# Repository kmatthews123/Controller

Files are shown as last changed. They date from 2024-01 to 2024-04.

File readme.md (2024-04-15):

# Custom ROV Controller

###### What is this project?

I designed this controller as a combination of work project and learning tool

The original genesis of this project was a whacky controller thought up during many long hours of driving with myself and a co-worker. I decided to build a custom ROV controller based on a guitar hero controller for laughs. The controller was a lot easier to build than I thought it would be and it was a very fun thing at my work Christmas party. 

The Guitar hero controller utilized all the buttons used by default on the guitar, I had to add a linear Potentiometer for the vertical propellor as well as the "whammy bar" as a self centering vertical propellor controller. I also added the joystick to the guitar. This was a fun project and while I did learn some stuff about circuit python I defiantly did not plan to use this for more than a gag.

#### The Real Controller



This controller was designed for use with a video ray pro4 ROV as a more comfortable and normal user interface device.

 I work at a company that uses a pro4 to inspect submerged structures. I found that the default controller from Video Ray is really uncomfortable to use for a full day and its design made it difficult for me to use during complex movements and actions. The  original controller (seen below)  shows up as a USB game-pad to the laptop that is used to communicate with the ROV. This computer uses windows 10 and using the USB controller utility included in windows I was able to map out how the video ray controller button map is seen by the system. From what I understand the pro4 has two compatible controllers, the normal industrial controller that my company normally uses and also the Logitech Cordless RumblePad 2 which is an old controller. Apparently you can edit xml files to make other controllers work with the pro4 but as engineering support has ended for this bot, I was left with the options of editing xml files that could potentially make my pro4 console unusable if i did something wrong (not an option as this is a work machine), download software to  remap the controller using software (This option was unappealing because I found this kind of software to be really hit and miss for the functions that I needed to setup) or design my own custom controller. 

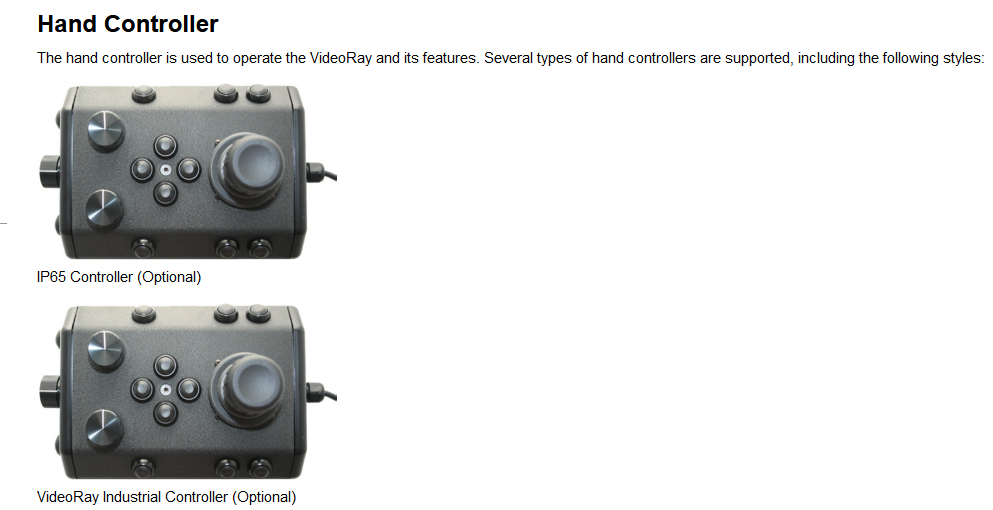
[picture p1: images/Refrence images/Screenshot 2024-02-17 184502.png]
Videoray default controller


I learned to use KiCAD 7.0 to design the custom PCB for this project. I have dabbled with electronics and code for years and have made several custom breadboards but the step to making my own distinct PCB was really interesting. The community for KiCad was very beginner friendly, and once I started to understand the structure of the program and the workflow the process began to make a lot of sense. I did do two different versions of this board. with the first version I was manually routing traces between my components and I realized that that was going to take way too long and for this application it didn't make much sense so I ended up auto routing the rest of the project. This worked fine though I do think that there are definitely routing things I could have improved.

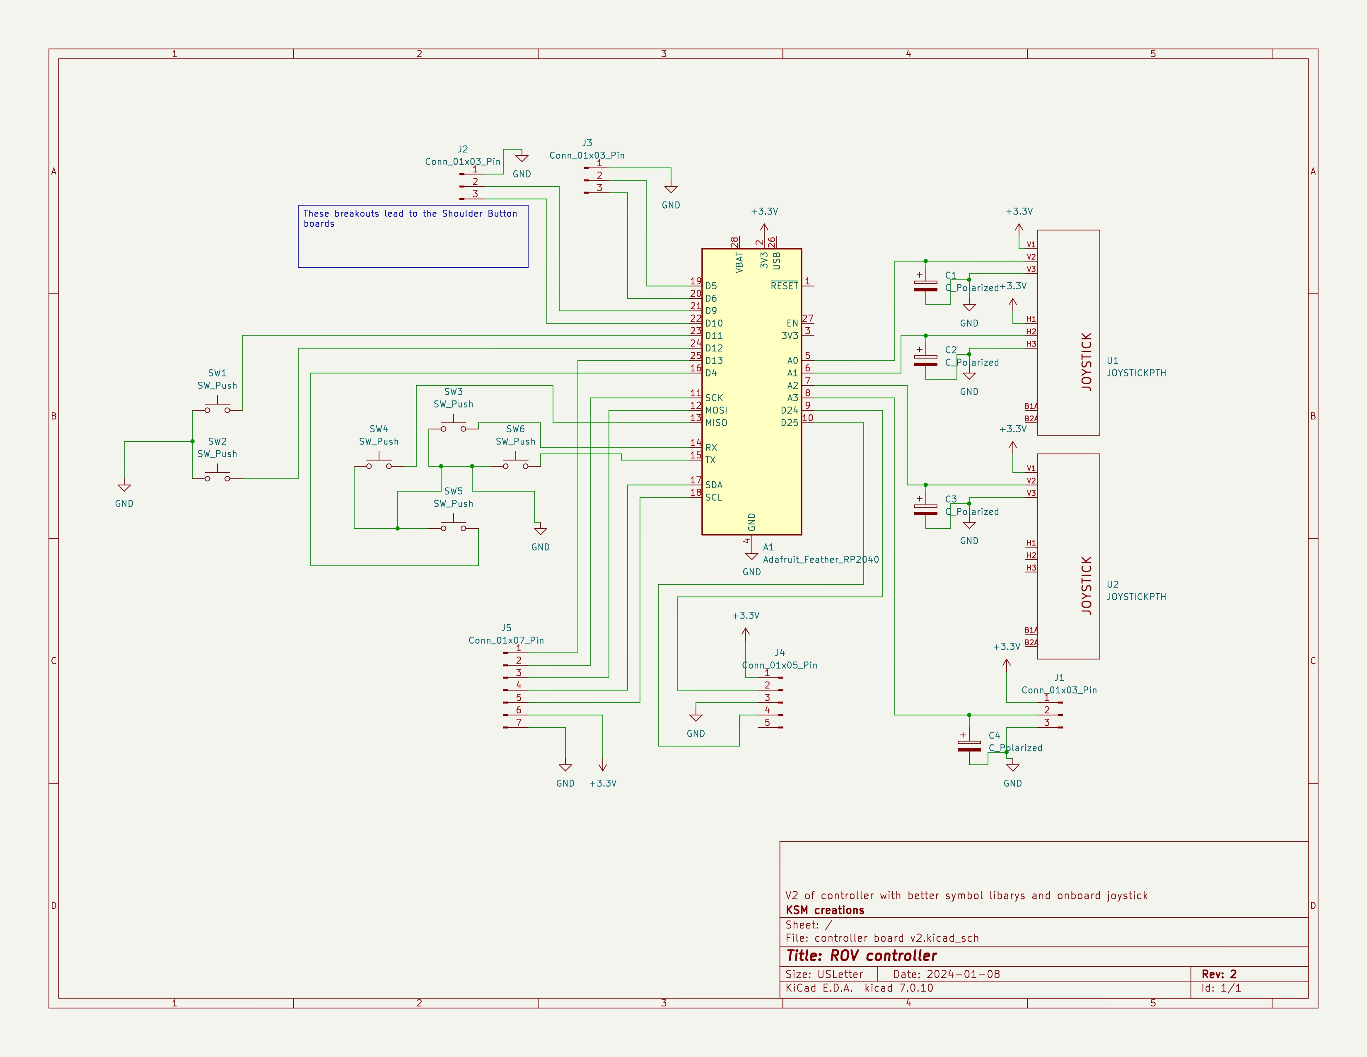
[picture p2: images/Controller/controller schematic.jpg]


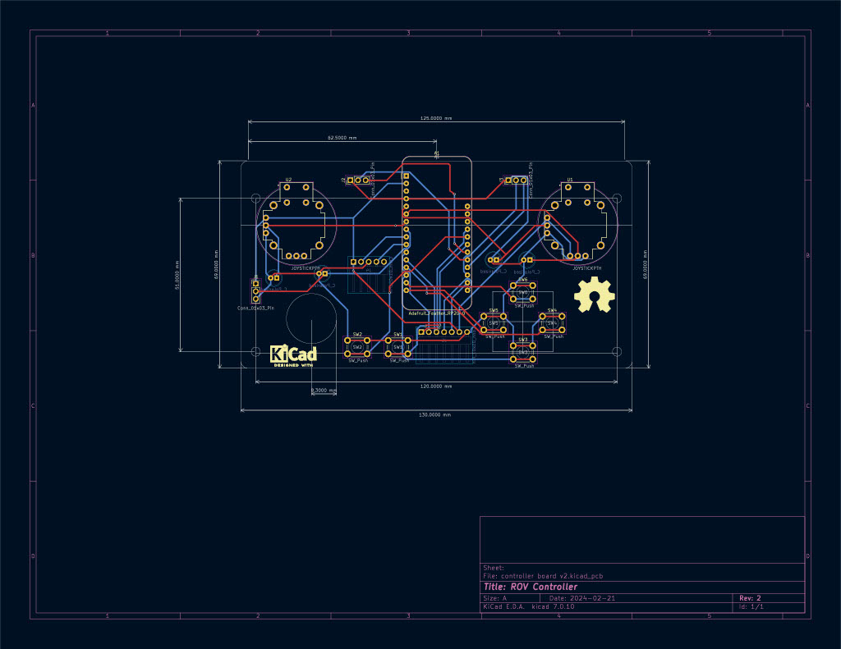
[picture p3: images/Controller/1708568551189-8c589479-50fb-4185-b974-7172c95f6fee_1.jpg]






 I also did not know how PCB manufacturers price out boards based on the amount of area that each board will take up in the batching process. Because of these things I found that I could save a bunch of money by making two distinct boards with one being the primary controller and the other being used for the shoulder buttons. the shoulder button board breaks in half for each side of the controller and everything is "wired" up really simply. I think adding an I2C analog input expansion board would have been a useful addition for this board (more on that later). I used OSH Park ~ for my PCB manufacturer because it was super easy to upload my KiCAD files to get them manufactured and the quality seems to be very good of the received circuit boards.

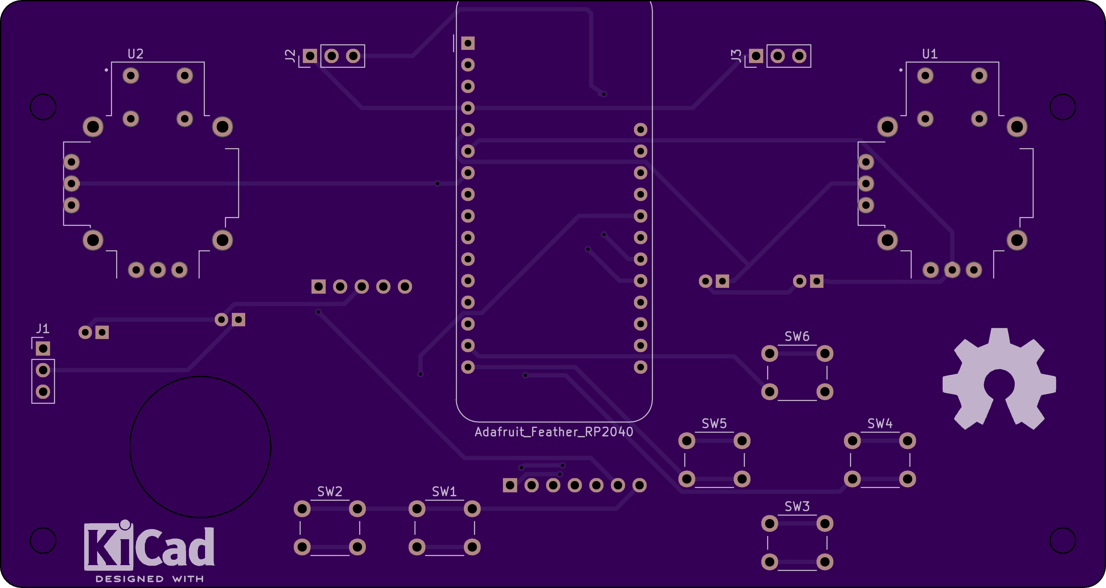
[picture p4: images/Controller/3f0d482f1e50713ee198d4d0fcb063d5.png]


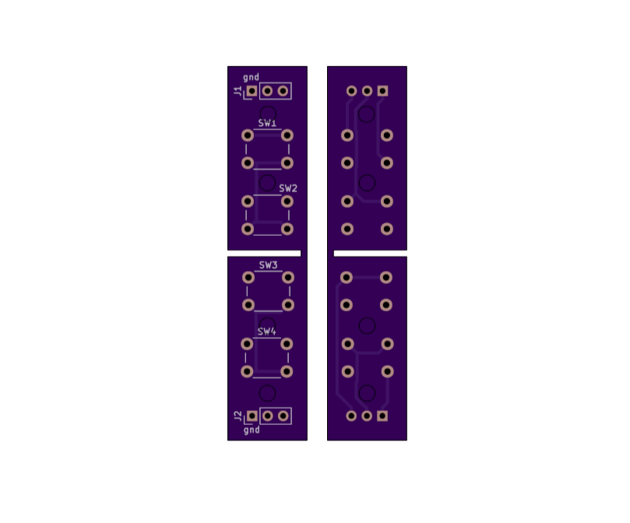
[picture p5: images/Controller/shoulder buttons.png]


For designing the body of the controller, I used an online CAD program called OnShape. I took a fairly simple approach to this and imported all the boards and as many components as i could find models for, then built an assembled circuit board in an assembly. From there I used dimensions of the board to layout the base of the controller, and designed the front plate as a piece used to hold the shoulder buttons. The shoulder buttons are admittedly a bit rough; I considered a bunch of different ways of designing the buttons and I think the method I used is ok if I had executed it a bit better. If I were to do a full redesign I would probably do something more similar to paddles instead of the straight push buttons I ended up with. Lastly I designed the face plate of the controller based off the PCB assembly I had built before. OnShape has a really neat feature that allows for referencing assemblies in a part design workflow. this was really handy for designing parts in reference to other more complicated items. 

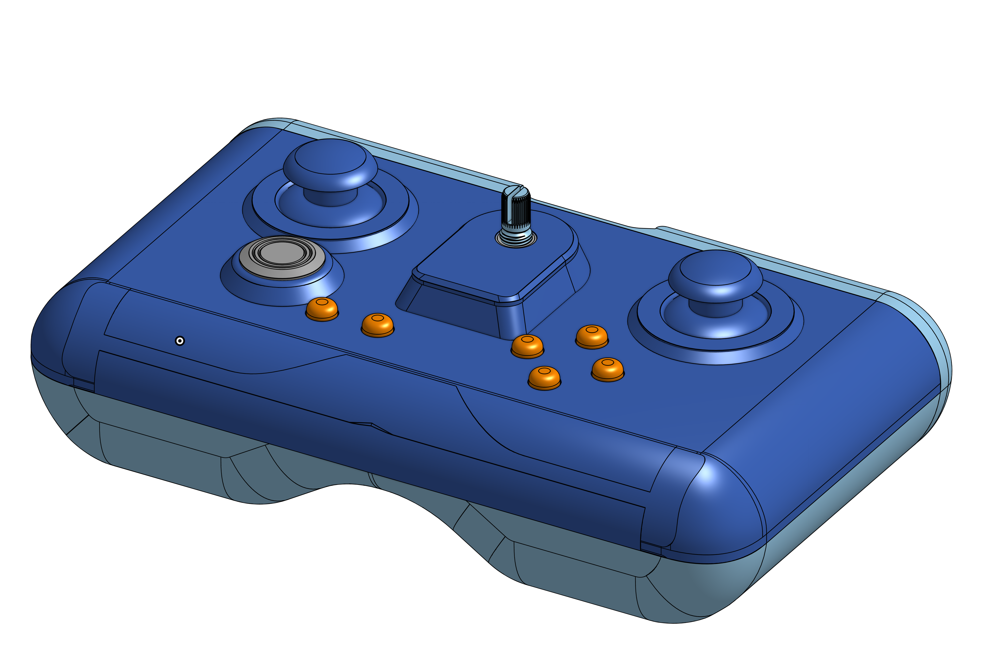
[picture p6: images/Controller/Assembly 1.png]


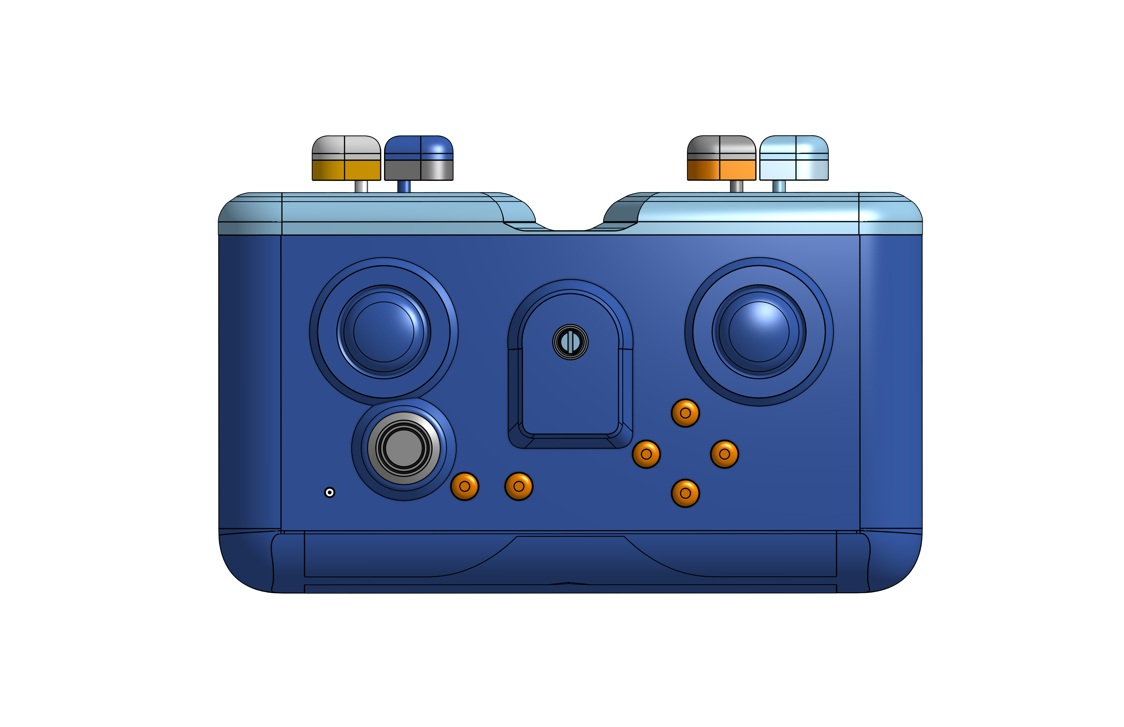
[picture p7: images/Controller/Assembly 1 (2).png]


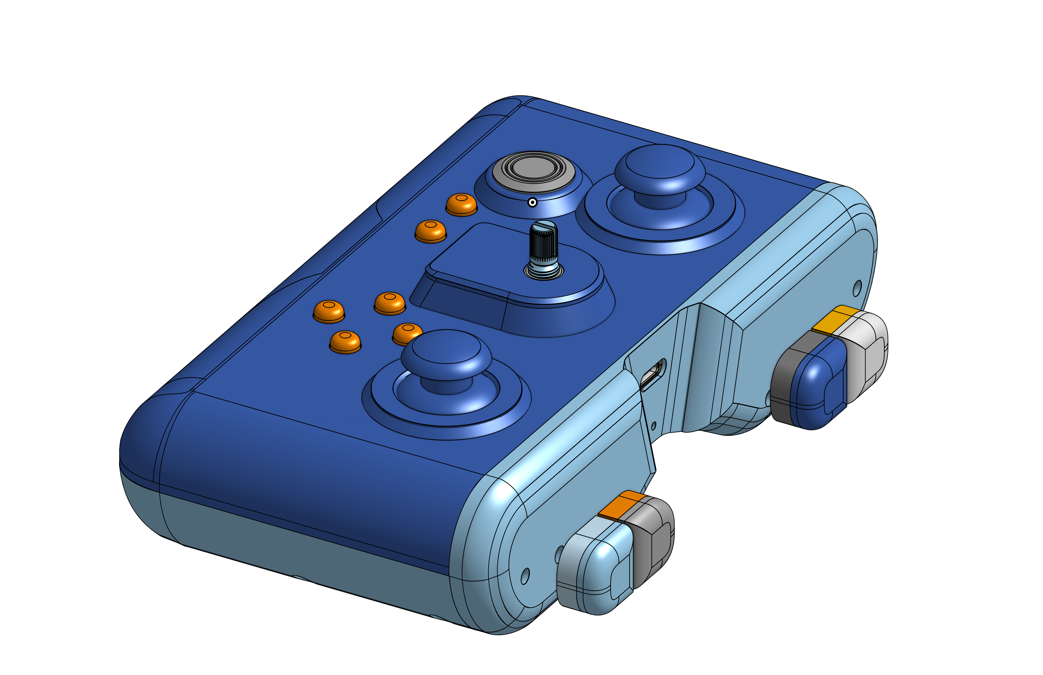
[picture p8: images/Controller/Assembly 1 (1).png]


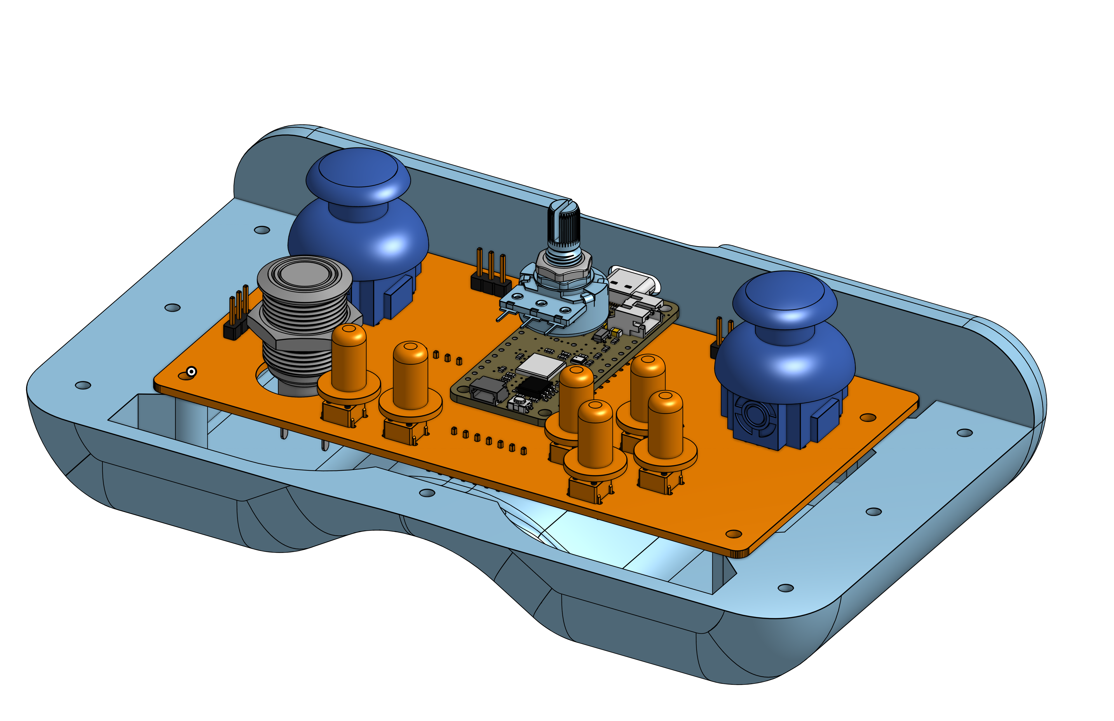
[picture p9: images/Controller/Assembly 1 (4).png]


The CAD for this project is available in the 3d Models folder for both .step files and .3mf files. To view, copy and mess around with my original cad models checkout the below OnShape link.

https://cad.onshape.com/documents/9419f7314355fc0529143749/w/7dd750f9077cb0f159653e8e/e/9448de140bcc603a1d0b7df0

###### The electronics used

- RP2040 Adafruit Feather board

- with generic joysticks bought on digikey (COM-09032),

-  10 generic push buttons (6mm button height),

-  4 electrolytic capacitors to smooth joystick motion (47 Farad) 

- 1 10k linear POT. 

- an assortment of DuPont headers

###### The code!

The code for this project relies heavily on an awesome library called 
joystick_XL for circuit python. if you want to build a project like this one a great starting point is this GitHub and associated documentation.

 [GitHub - fasteddy516/CircuitPython_JoystickXL: Turn a CircuitPython device into a joystick controller with lots of inputs.](https://github.com/fasteddy516/CircuitPython_JoystickXL) 

I also ended up using some logic to switch inputs from a joystick on the right side to the potentiometer in the middle of the controller. This switch is useful because I found that I wanted a self centering vertical thruster control. For the Pro4 this means that when you are not actively using the controller the vertical propellor will be off. We set the pro4 to be neutrally buoyant when in fresh water. If you want to use the vertical propellor when not actually touching the controller (very useful for certain actions, motions and when lifting on items during an inspection). 

For those unfamiliar with the somewhat complicated process of building a USB HID device this library and circuit python in general makes things really easy. I can see lots of use cases for this library with all manner of custom interface devices and I could see this project acting as a good starting point for anyone trying to do something similar.

If you have a pro4 or another Video Ray device, there are a few changes I would make before trying to replicate this project 1:1. I don't plan on doing that for myself, but please reach out if you want to make your own, as I wouldn't mind sharing thoughts on an improved v2.

###### Lessons Learned and things to improve

- I should have used a micro controller with one additional analog input pin. This would have added flexibility for modifying the controller config. I find that I want to use the left hand controller for vertical movement and also for yaw and using the right stick for going forward and back. The current controller doesn't have the Y axis on the left hand stick connected to anything currently because I had to have the set and forget vertical propellor as an option. I think next time I would use something more like the Adafruit Feather M4 Express as it would have enough digital pins and enough analog IO to get the job done. this micro controller is a bit more spendy and I could also see using the Adafruit Feather 32u4 as a cheaper alternative. Basically something with the same pinout and more analog pins while still having at least 12 digital pins onboard. 

- The shoulder buttons are not very good. I think I could have planned those better and I think that next time I would use something more like a standard keyboard switch for the shoulder buttons or something like a simple paddle that would push on the head of a simple button. 

- I would like to explore a wireless version of this device at some point but this is pretty far down my list of priorities. 



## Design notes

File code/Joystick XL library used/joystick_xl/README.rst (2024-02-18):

JoystickXL for CircuitPython
============================








Description
===========
This CircuitPython driver simulates a *really big* USB HID joystick device - up
to 8 axes, 128 buttons and 4 hat (POV) switches.  If you want to build a custom
game controller with a lot of inputs - *I'm looking at you, space/flight sim
pilots, racing sim drivers and virtual farmers* - JoystickXL can help.

Requirements
============
*This driver relies on features that were introduced in CircuitPython
version 7.x*  **You must be running CircuitPython 7.0.0 or newer
on your device in order to use JoystickXL.**

* This driver was made for devices running `Adafruit CircuitPython <https://www.adafruit.com/circuitpython>`_.
  For a list of compatible devices, see `circuitpython.org <https://circuitpython.org/downloads>`_.

* There are no dependencies on any other CircuitPython drivers, libraries or modules.

* Pre-compiled (``.mpy``) versions of JoystickXL are available in the `releases <https://github.com/fasteddy516/CircuitPython_JoystickXL/releases>`_
  section for CircuitPythons version 8.x and 9.x.  

Limitations
===========
* A wired USB connection to the host device is required.  *Bluetooth
  connectivity is not supported at this time.*

* Axis data is reported with 8-bit resolution (values ranging from 0-255).

* Only one JoystickXL device can be defined per CircuitPython board.  *You
  cannot have a single board report as two or more independant joysticks.*

* JoystickXL's reporting frequency - thus, input latency - is affected by
  many factors, including processor speed, the number of inputs that need
  to be processed, and the latency of any external input peripherals that
  are being used.  The reporting frequency is going to be significantly
  higher on a Metro M4 Express using on-board GPIO than it is on a QT-PY
  using I2C/SPI-based I/O expanders. 

Host OS/Software Compatibility
==============================
On **Windows 10/11**, all 8 axes 128 buttons and 4 hat switches are supported at
the operating system level, and JoystickXL has been tested and confirmed to work
with the following games:

* **Microsoft Flight Simulator (2020)** *(All inputs)*
* **Elite Dangerous** *(Limited to 32 buttons)*
* **Star Citizen** *(All inputs)*
* **Digital Combat Simulator (DCS) World** *(All inputs)*
* **EverSpace 2** *(All inputs - hat switches are considered to be axes)*
* **Forza Horizon 4** *(All inputs)*
* **BeamNG.drive** *(Limited to 7 axes and 1 hat switch)*
* **Farming Simulator 19** *(Limited to 7 axes, 24 buttons and 1 hat switch)*

*Note that any game-specific input limitations mentioned above are - to the
best of my knowledge - a result of the game's joystick implementation, and are
not unique to JoystickXL.*

On **Linux**, a very limited amount of testing has been done on a Raspberry Pi
4B using ``jstest`` (part of the ``joystick`` package).  The first 7 axes and
80 buttons work correctly.  Axis 8 does not register any events, nor do any
buttons beyond the first 80.  Only a single hat switch *sort of* works, but it
gets interpreted as two axes rather than an actual hat switch.  Other Linux
platforms/distributions/applications have not been tested.

No testing has been done on an **Apple/Mac** platform.

Documentation
=============
Full documentation is available at `<https://circuitpython-joystickxl.readthedocs.org>`_.

Installation
============
1. Download the `latest release of JoystickXL <https://github.com/fasteddy516/CircuitPython_JoystickXL/releases/latest>`_
   that corresponds to the version of CircuitPython you're running.  (i.e.
   ``joystick_xl_x.x.x_cp8`` for CircuitPython 8.x)
2. Extract the files from the downloaded .zip archive.
3. Copy the ``joystick_xl`` folder to the ``lib`` folder on your device's
   ``CIRCUITPY`` drive.

For additional information on installing libraries, see Adafruit's
`Welcome to CircuitPython Guide <https://learn.adafruit.com/welcome-to-circuitpython/circuitpython-libraries>`_.

Using JoystickXL
================
1. Create/modify ``boot.py`` on your CircuitPython device to enable the
   required custom USB HID device.

   .. code:: python

      """boot.py"""
      import usb_hid
      from joystick_xl.hid import create_joystick

      # enable default CircuitPython USB HID devices as well as JoystickXL
      usb_hid.enable(
        (
          usb_hid.Device.KEYBOARD,
          usb_hid.Device.MOUSE,
          usb_hid.Device.CONSUMER_CONTROL,
          create_joystick(axes=2, buttons=2, hats=1),
        )
      )

2. Use JoystickXL in ``code.py`` like this:

   .. code:: python
     
      """code.py"""
      import board
      from joystick_xl.inputs import Axis, Button, Hat
      from joystick_xl.joystick import Joystick
   
      js = Joystick()
   
      js.add_input(
          Button(board.D9),
          Button(board.D10),
          Axis(board.A2),
          Axis(board.A3),
          Hat(up=board.D2, down=board.D3, left=board.D4, right=board.D7),
      )

      while True:
          js.update()

   See the `examples <https://circuitpython-joystickxl.readthedocs.io/en/latest/examples.html>`_
   and `API documentation <https://circuitpython-joystickxl.readthedocs.io/en/latest/api.html>`_
   for more information.

Testing JoystickXL Devices
==========================
Not all platforms/games/applications support joystick devices with high input
counts.  **Before you spend any time writing code or building hardware for a
custom controller, you should make sure the software that you want to use it
with is compatible.**

Fortunately, JoystickXL has a built-in testing module that can be run right
from the CircuitPython Serial Console/REPL to verify compatibility with an
operating system, game or application - *no input wiring or code.py required!*

See the
`compatibility and testing documentation <https://circuitpython-joystickxl.readthedocs.io/en/latest/start.html#verifying-compatibility>`_
for more information.

Contributing
============
If you have questions, problems, feature requests, etc. please post them to the 
`Issues section on Github <https://github.com/fasteddy516/CircuitPython_JoystickXL/issues>`_.
If you would like to contribute, please let me know.

Acknowledgements
============================
A massive thanks to Adafruit and the entire CircuitPython team for creating and
constantly improving the CircuitPython ecosystem.  

Frank Zhao's 
`Tutorial about USB HID Report Descriptors <https://eleccelerator.com/tutorial-about-usb-hid-report-descriptors/>`_
was the starting point for my journey into USB HID land.

The tools and documentation provided by the `USB Implementors Forum <https://www.usb.org/>`_
were an excellent resource, especially in regards to the creation of the
required USB HID descriptor.  The following resources were particularly useful:

* `HID Descriptor Tool <https://www.usb.org/document-library/hid-descriptor-tool>`_
* `Device Class Definition for HID <https://www.usb.org/document-library/device-class-definition-hid-111>`_
* `HID Usage Tables <https://www.usb.org/document-library/hid-usage-tables-122>`_

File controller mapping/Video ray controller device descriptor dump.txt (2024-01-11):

Information for device VideoRay Controller (VID=0x16C0 PID=0x27B5):

------------------------------
Connection Information:
------------------------------
Device current bus speed: FullSpeed
Device supports USB 1.1 specification
Device supports USB 2.0 specification
Device address: 0x0002
Current configuration value: 0x01
Number of open pipes: 1

------------------------------
Device Descriptor:
------------------------------
0x12	bLength
0x01	bDescriptorType
0x0200	bcdUSB
0x00	bDeviceClass      
0x00	bDeviceSubClass   
0x00	bDeviceProtocol   
0x40	bMaxPacketSize0   (64 bytes)
0x16C0	idVendor
0x27B5	idProduct
0x0121	bcdDevice
0x01	iManufacturer   "VideoRay, LLC"
0x02	iProduct        "VideoRay Controller"
0x03	iSerialNumber   "B71756"
0x01	bNumConfigurations

-------------------------
Configuration Descriptor:
-------------------------
0x09	bLength
0x02	bDescriptorType
0x0022	wTotalLength   (34 bytes)
0x01	bNumInterfaces
0x01	bConfigurationValue
0x00	iConfiguration
0x80	bmAttributes   (Bus-powered Device)
0x32	bMaxPower      (100 mA)

Interface Descriptor:
------------------------------
0x09	bLength
0x04	bDescriptorType
0x00	bInterfaceNumber
0x00	bAlternateSetting
0x01	bNumEndPoints
0x03	bInterfaceClass      (Human Interface Device Class)
0x00	bInterfaceSubClass   
0x00	bInterfaceProtocol   
0x00	iInterface

HID Descriptor:
------------------------------
0x09	bLength
0x21	bDescriptorType
0x0110	bcdHID
0x00	bCountryCode
0x01	bNumDescriptors
0x22	bDescriptorType   (Report descriptor)
0x0067	bDescriptorLength

Endpoint Descriptor:
------------------------------
0x07	bLength
0x05	bDescriptorType
0x81	bEndpointAddress  (IN endpoint 1)
0x03	bmAttributes      (Transfer: Interrupt / Synch: None / Usage: Data)
0x0020	wMaxPacketSize    (1 x 32 bytes)
0x04	bInterval         (4 frames)

Microsoft OS Descriptor is not available. Error code: 0x0000001F

--------------------------------
String Descriptor Table
--------------------------------
Index  LANGID  String
0x00   0x0000  0x0409 
0x01   0x0409  "VideoRay, LLC"
0x02   0x0409  "VideoRay Controller"
0x03   0x0409  "B71756"

------------------------------

Connection path for device: 
USB xHCI Compliant Host Controller
Root Hub
VideoRay Controller (VID=0x16C0 PID=0x27B5) Port: 1

Running on: Windows 10 or greater (Build Version 22631)

Brought to you by TDD v2.17.0, Feb 23 2021, 14:04:02

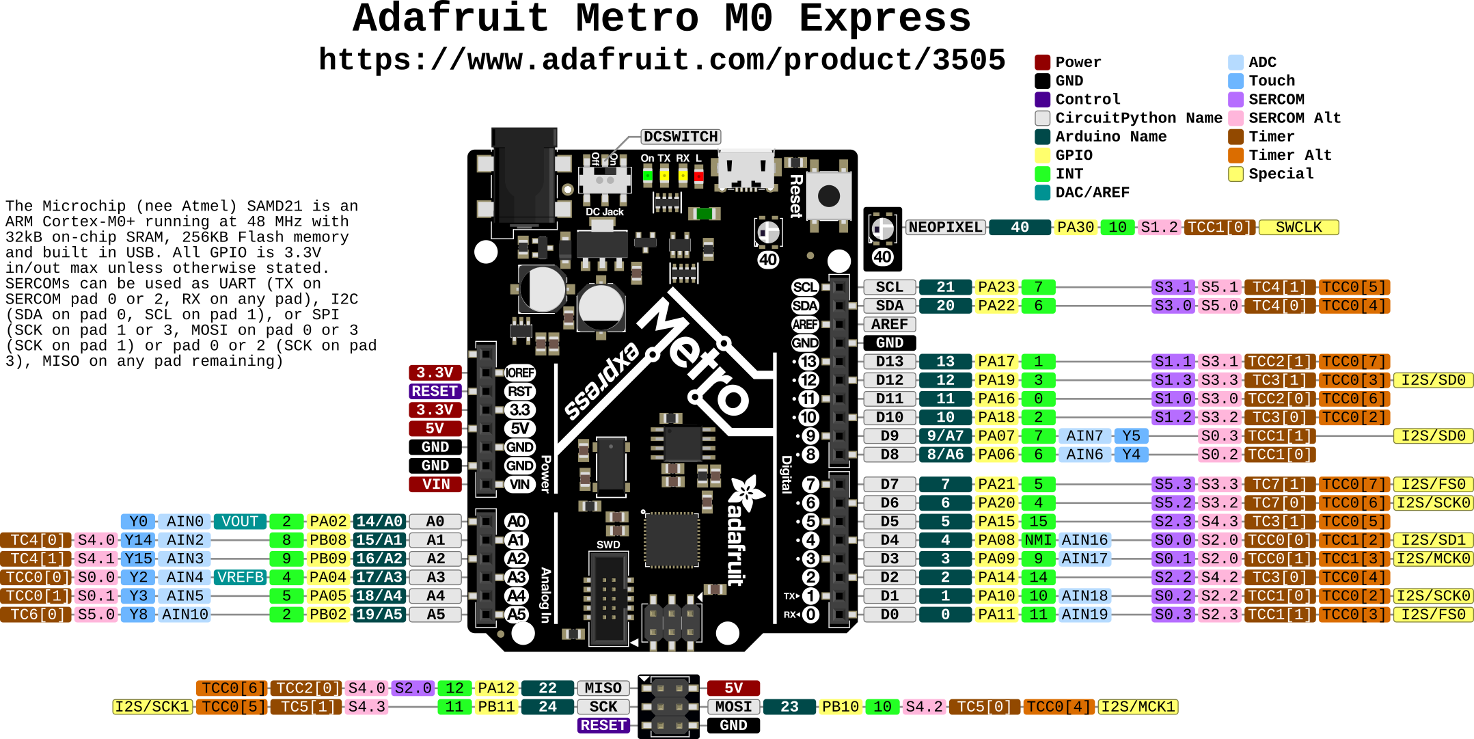
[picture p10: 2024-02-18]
images/Refrence images/circuitpython_Adafruit_Metro_M0_Express_Pinout.png

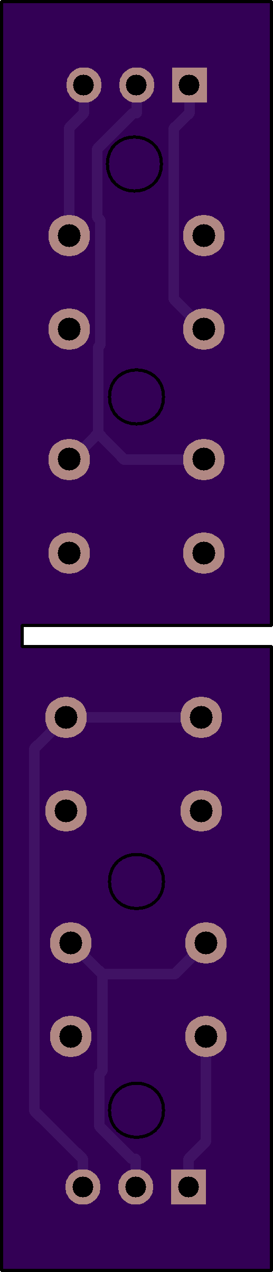
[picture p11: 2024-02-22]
images/Controller/fd5e066b961b53b54e37cfb2f9c67ee4.png

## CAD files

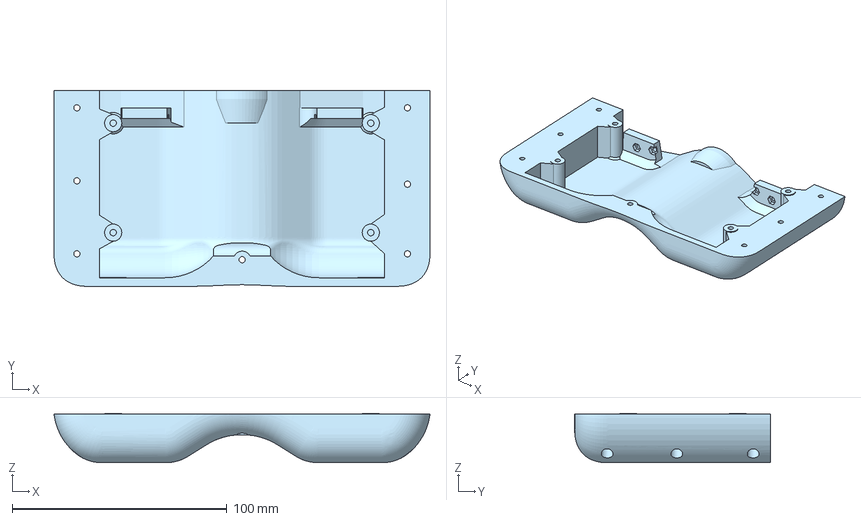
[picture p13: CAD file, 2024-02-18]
3d models/controller body 3d print files/Controller body - Base.3mf
175.1 x 91.1 x 23.0 mm

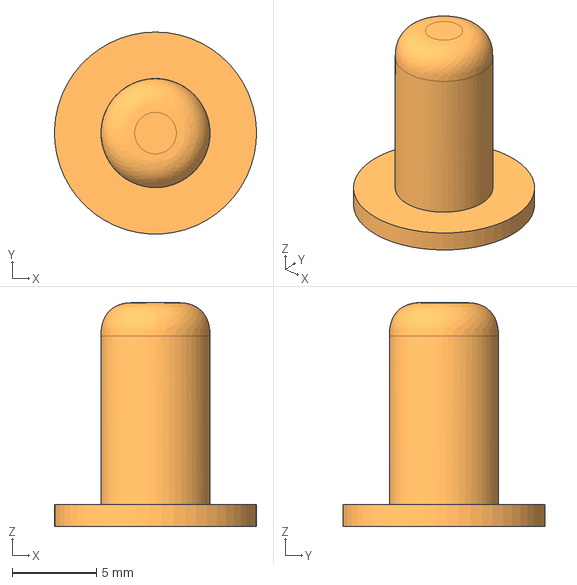
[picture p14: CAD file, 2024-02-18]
3d models/Controller Parts for 3D Print/Controller body - button.step
12.0 x 12.0 x 13.3 mm

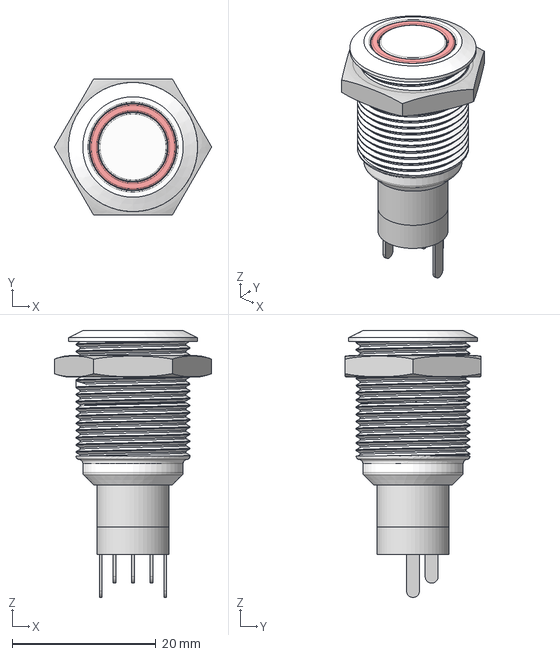
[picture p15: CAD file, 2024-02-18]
3d models/Files for refrence/916 Metal Button 19mm metal button, on off switch.step
21.9 x 19.0 x 37.2 mm

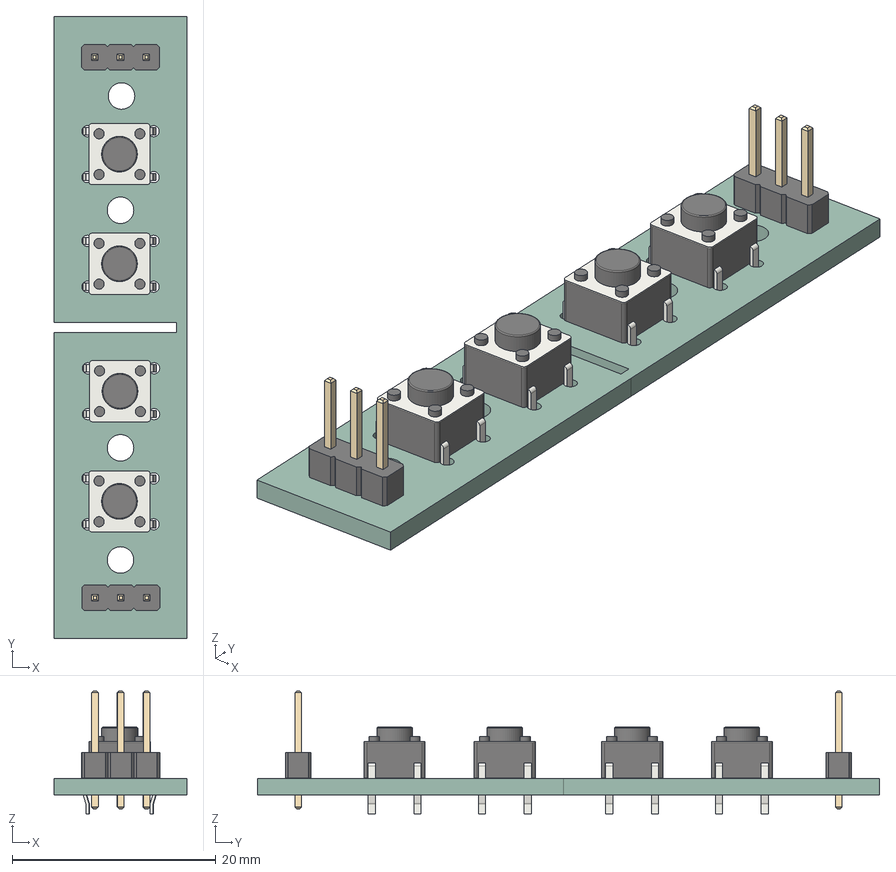
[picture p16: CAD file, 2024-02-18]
board_shematic/controller board V2/controller board v2/controller board sholder buttons/controller board sholder buttons.step
13.0 x 61.0 x 12.0 mm
SW_PUSH_6mm_h5mm x 4
PinHeader_1x03_P254mm_Vertical x 2
_autosave-controller board sholder buttons PCB

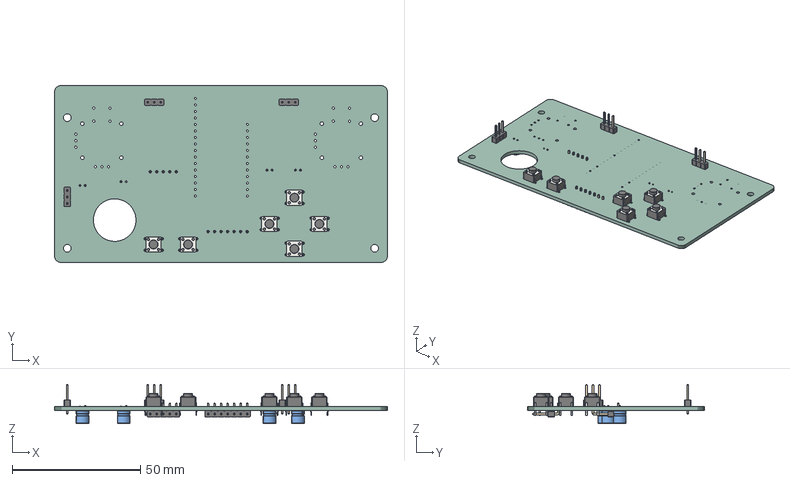
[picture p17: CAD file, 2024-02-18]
board_shematic/controller board V2/controller board v2/controller board v2.step
130.0 x 69.0 x 15.2 mm
SW_PUSH_6mm_h5mm x 6
PinHeader_1x03_P254mm_Vertical x 3
CP_Radial_D50mm_P200mm x 4
PinHeader_1x05_P254mm_Horizontal
PinHeader_1x07_P254mm_Horizontal
controller board v2 PCB

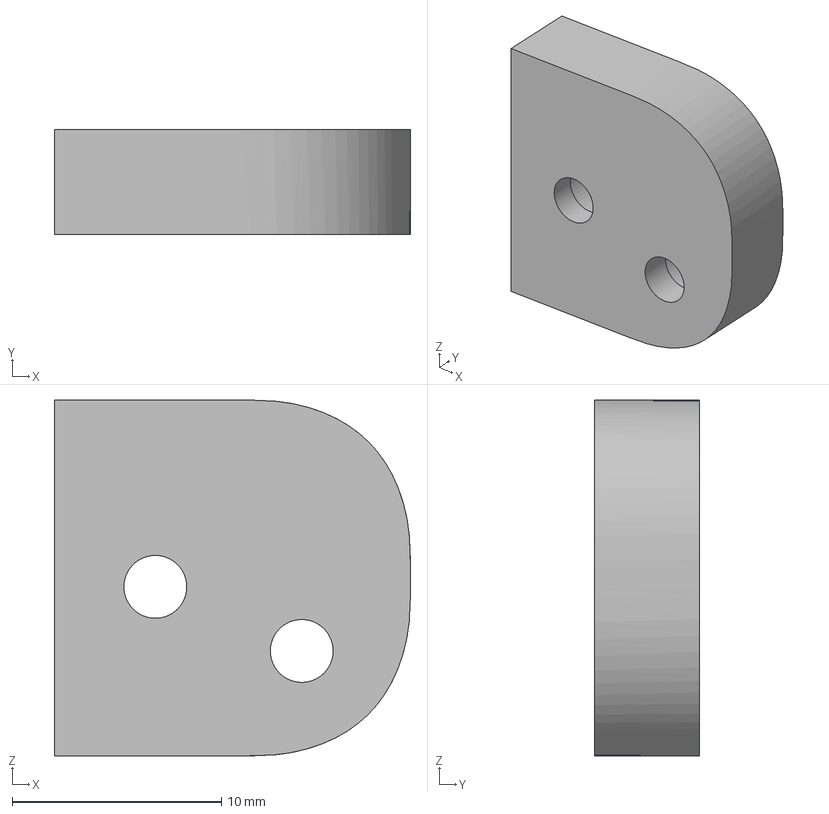
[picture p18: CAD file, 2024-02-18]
3d models/controller body 3d print files/Sholder buttons - left2.3mf
17.0 x 5.01 x 17.0 mm

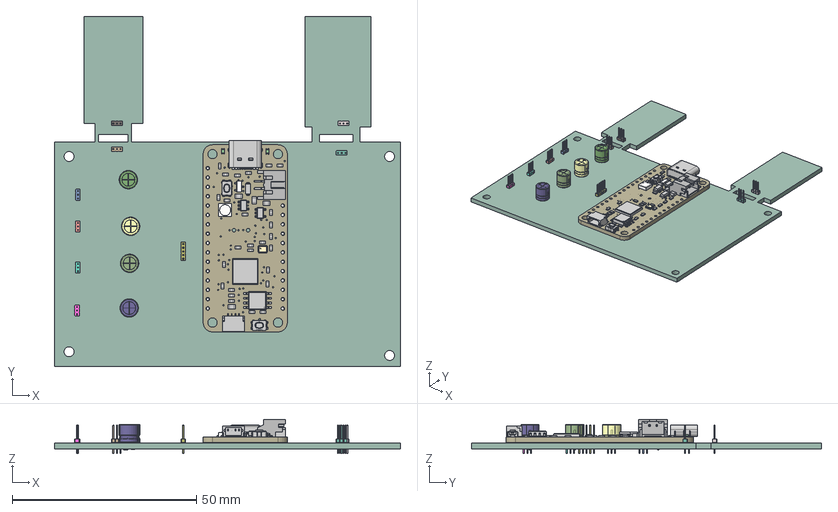
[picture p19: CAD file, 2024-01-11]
3d models/Files for refrence/Early controller design.FCStd
94.0 x 95.0 x 9.35 mm
PinHeader_1x03_P100mm_Vertical
PinHeader_1x03_P100mm_Vertical001
PinHeader_1x05_P100mm_Vertical
PinHeader_1x03_P100mm_Vertical002
CP_Radial_D50mm_P200mm
CP_Radial_D50mm_P200mm001
PinHeader_1x03_P100mm_Vertical003
PinHeader_1x03_P100mm_Vertical004
PinHeader_1x03_P100mm_Vertical005
PinHeader_1x03_P100mm_Vertical006
PinHeader_1x03_P100mm_Vertical007
CP_Radial_D50mm_P200mm002
CP_Radial_D50mm_P200mm003
_autosave-controller board PCB
Board
0805-NO
0805-NO001
0805-NO002
0805-NO003
CHIPLED_0603_NOOUTLINE
CHIPLED_0603_NOOUTLINE001
CHIPLED_0603_NOOUTLINE002
CHIPLED_0603_NOOUTLINE003
CHIPLED_0603_NOOUTLINE004
CHIPLED_0603_NOOUTLINE006
CHIPLED_0603_NOOUTLINE007
CHIPLED_0603_NOOUTLINE008
CHIPLED_0603_NOOUTLINE009
CHIPLED_0603_NOOUTLINE010
0603-NO
0603-NO001
0603-NO002
0603-NO003
0603-NO004
0603-NO005
0603-NO006
0603-NO007
0603-NO008
0603-NO009
0603-NO010
0603-NO011
0603-NO012
0603-NO013
0603-NO014
0603-NO015
0603-NO016
0603-NO017
0603-NO018
0603-NO019
0603-NO020
0603-NO021
0603-NO022
0603-NO023
0603-NO024
0603-NO025
BTN_KMR2_4.6X2.8
BTN_KMR2_4.6X2.009
SOT23-5@1
JSTPH2_BATT
JSTPH2_BATT001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

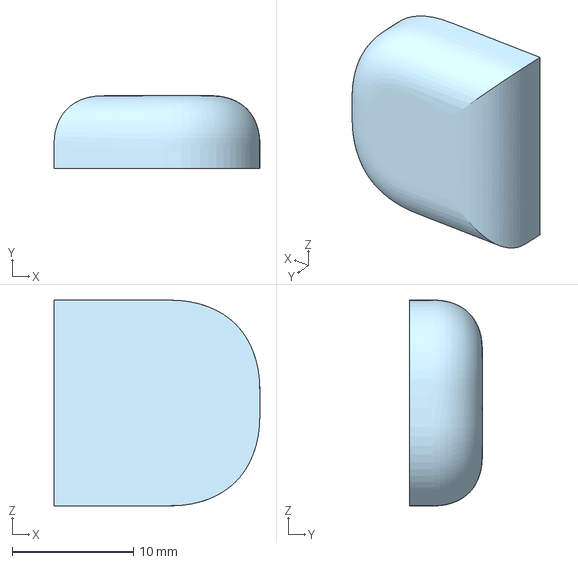
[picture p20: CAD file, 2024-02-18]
3d models/controller body 3d print files/Sholder buttons - button face right1.3mf
17.0 x 6.01 x 17.0 mm

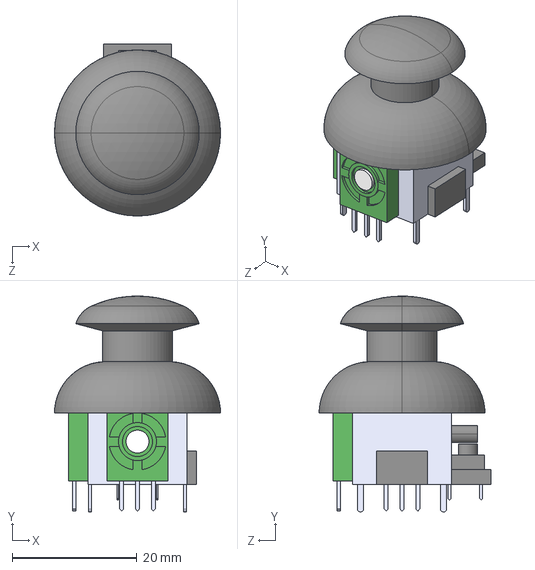
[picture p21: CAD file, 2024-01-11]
3d models/Files for refrence/COM-09032.step
26.7 x 34.7 x 27.6 mm

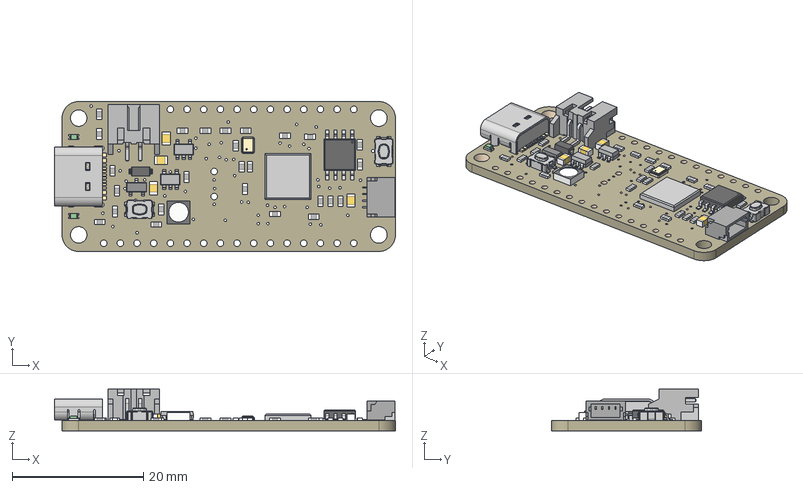
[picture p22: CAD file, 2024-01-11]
3d models/Files for refrence/4884 Feather RP2040.step
51.9 x 22.9 x 6.37 mm
Board
10uF x 4
ORANGE x 2
1K x 26
KMR2 x 2
AP2112-3.3
JSTPH
MCP73831T-2ACI/OT
WS2812B3535
2MB Flash
MBR540
DMG341
USB Type C
RP2040_QFN56
STEMMA_I2C_QT
12MHZ

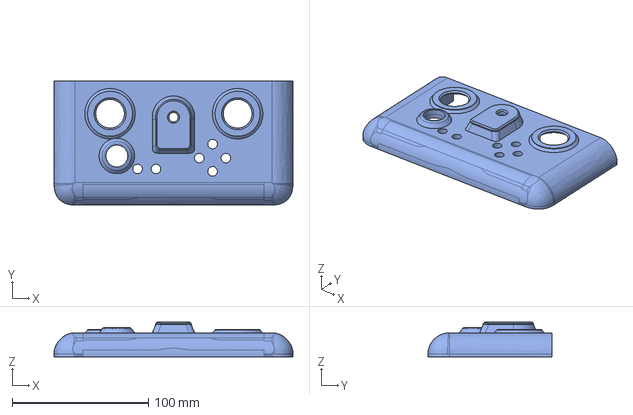
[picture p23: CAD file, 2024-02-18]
3d models/Controller Parts for 3D Print/Controller body - top shell.step
175.1 x 91.2 x 25.6 mm

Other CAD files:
3d models/Controller Parts for 3D Print/Sholder buttons - right2.step
3d models/Controller Parts for 3D Print/Sholder buttons - right1.step
3d models/controller body 3d print files/Sholder buttons - button face right2.3mf
3d models/Controller Parts for 3D Print/Sholder buttons - button face right2.step
3d models/controller body 3d print files/Sholder buttons - button face left2.3mf
3d models/controller body 3d print files/Sholder buttons - right2.3mf
3d models/Controller Parts for 3D Print/Controller body - Base.step
3d models/Controller Parts for 3D Print/Controller body - faceplate.step
3d models/Controller Parts for 3D Print/Sholder buttons - button face left1.step
3d models/Controller Parts for 3D Print/Sholder buttons - button face left2.step
3d models/Controller Parts for 3D Print/Sholder buttons - button face right1.step
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

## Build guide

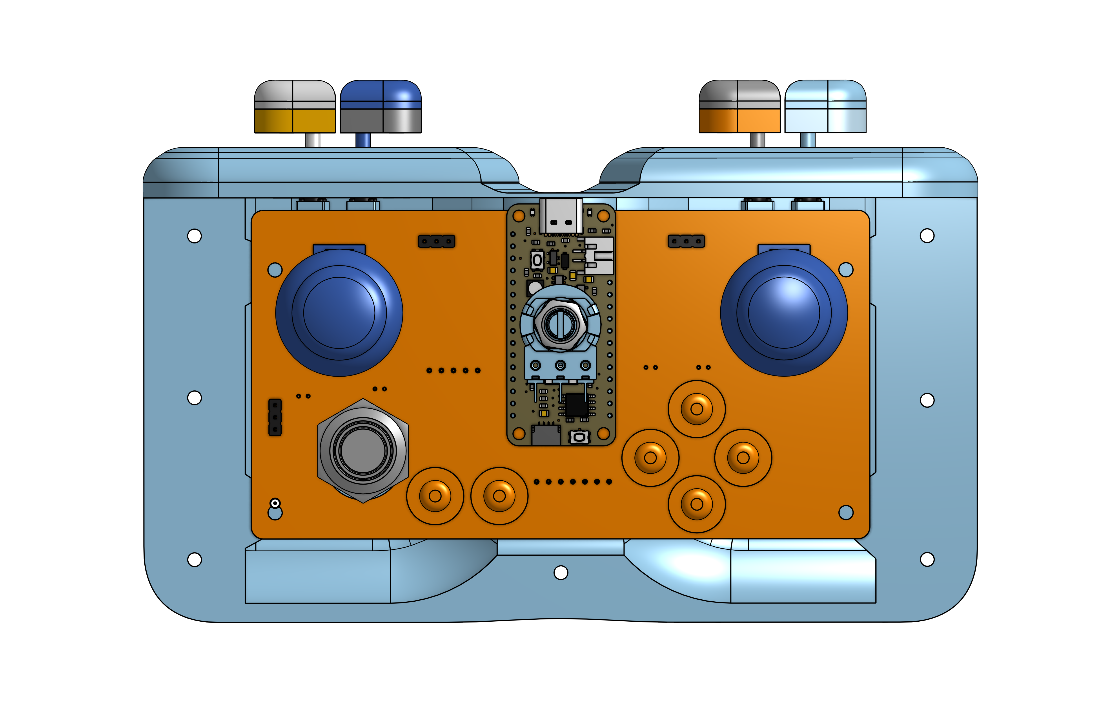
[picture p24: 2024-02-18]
images/Controller/Assembly 1 (3).png

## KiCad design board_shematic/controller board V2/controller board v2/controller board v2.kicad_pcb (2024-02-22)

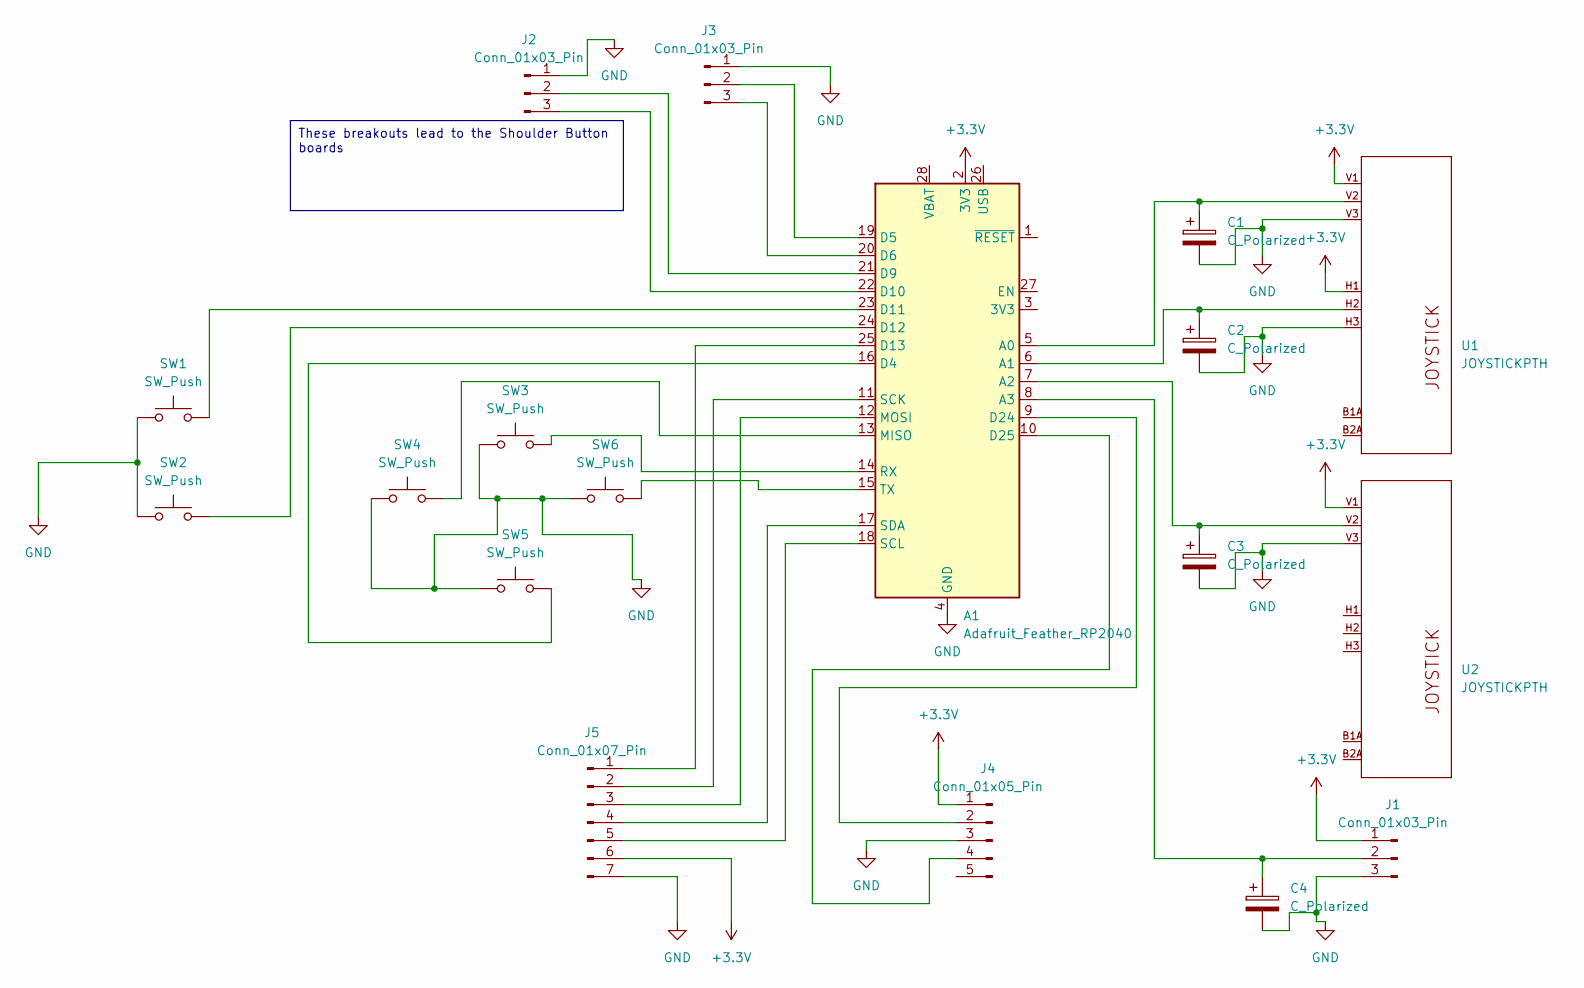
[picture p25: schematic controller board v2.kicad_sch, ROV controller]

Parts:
A1: Adafruit_Feather_RP2040; Adafruit_Feather
C1, C2, C3, C4: C_Polarized; CP_Radial_D5.0mm_P2.00mm
J1, J2, J3: Conn_01x03_Pin; PinHeader_1x03_P2.54mm_Vertical
J4: Conn_01x05_Pin; PinHeader_1x05_P2.54mm_Horizontal
J5: Conn_01x07_Pin; PinHeader_1x07_P2.54mm_Horizontal
SW1, SW2, SW3, SW4, SW5, SW6: SW_Push; SW_PUSH_6mm_H5mm
U1, U2: JOYSTICKPTH; XDCR_COM-09032

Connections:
+3.3V: A1.2 (3V3), J1.1, J4.1, J5.6, U1.H1 (H+), U1.V1 (V+), U2.V1 (V+)
GND: A1.4 (GND), C1.2, C2.2, C3.2, C4.2, J1.3, J2.1, J3.1, J4.3, J5.7, SW1.1, SW2.1, SW3.1, SW4.1, SW5.1, SW6.1, U1.H3 (H-), U1.V3 (V-), U2.V3 (V-)
unnamed: A1.5 (A0), C1.1, U1.V2 (V)
unnamed: A1.6 (A1), C2.1, U1.H2 (H)
unnamed: A1.7 (A2), C3.1, U2.V2 (V)
unnamed: A1.8 (A3), C4.1, J1.2
unnamed: A1.16 (D4), SW5.2
unnamed: A1.19 (D5), J3.2
unnamed: A1.20 (D6), J3.3
unnamed: A1.21 (D9), J2.2
unnamed: A1.22 (D10), J2.3
unnamed: A1.23 (D11), SW1.2
unnamed: A1.24 (D12), SW2.2
unnamed: A1.25 (D13), J5.1
unnamed: A1.9 (D24), J4.2
unnamed: A1.10 (D25), J4.4
unnamed: A1.13 (MISO), SW4.2
unnamed: A1.12 (MOSI), J5.3
unnamed: A1.14 (RX), SW3.2
unnamed: A1.11 (SCK), J5.2
unnamed: A1.18 (SCL), J5.5
unnamed: A1.17 (SDA), J5.4
unnamed: A1.15 (TX), SW6.2

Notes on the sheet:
These breakouts lead to the Shoulder Button boards

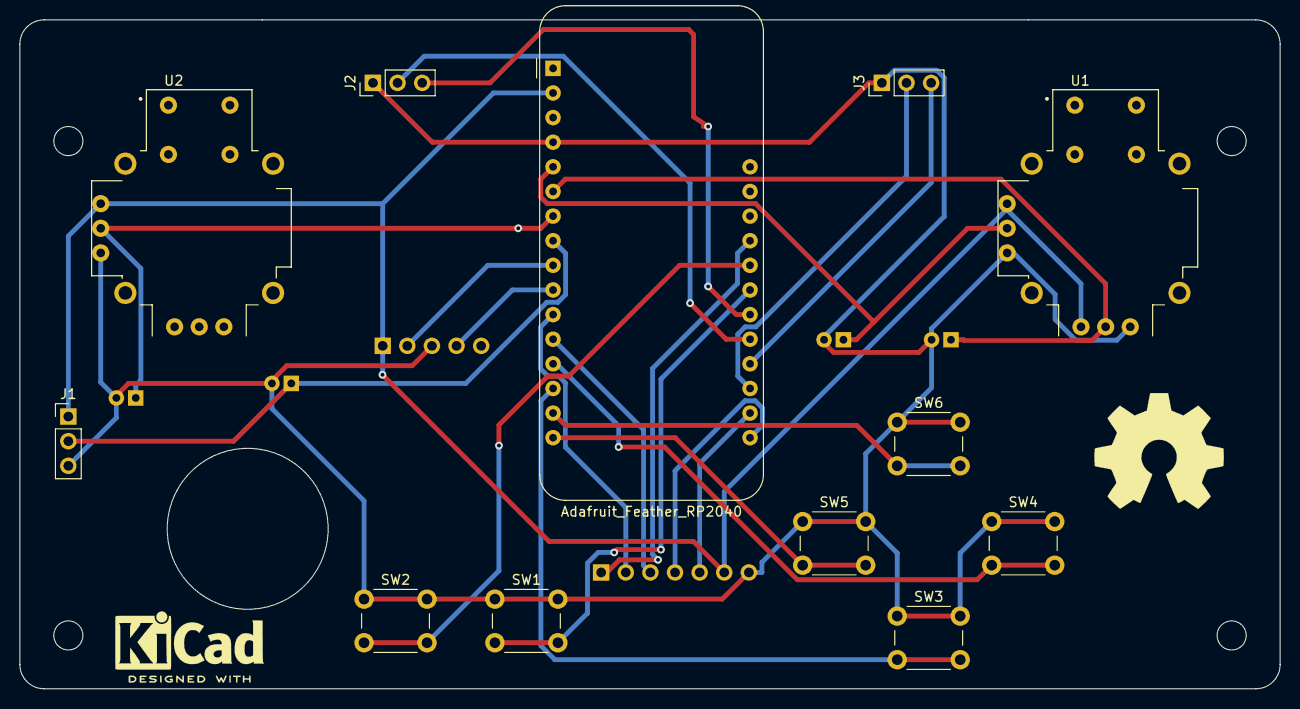
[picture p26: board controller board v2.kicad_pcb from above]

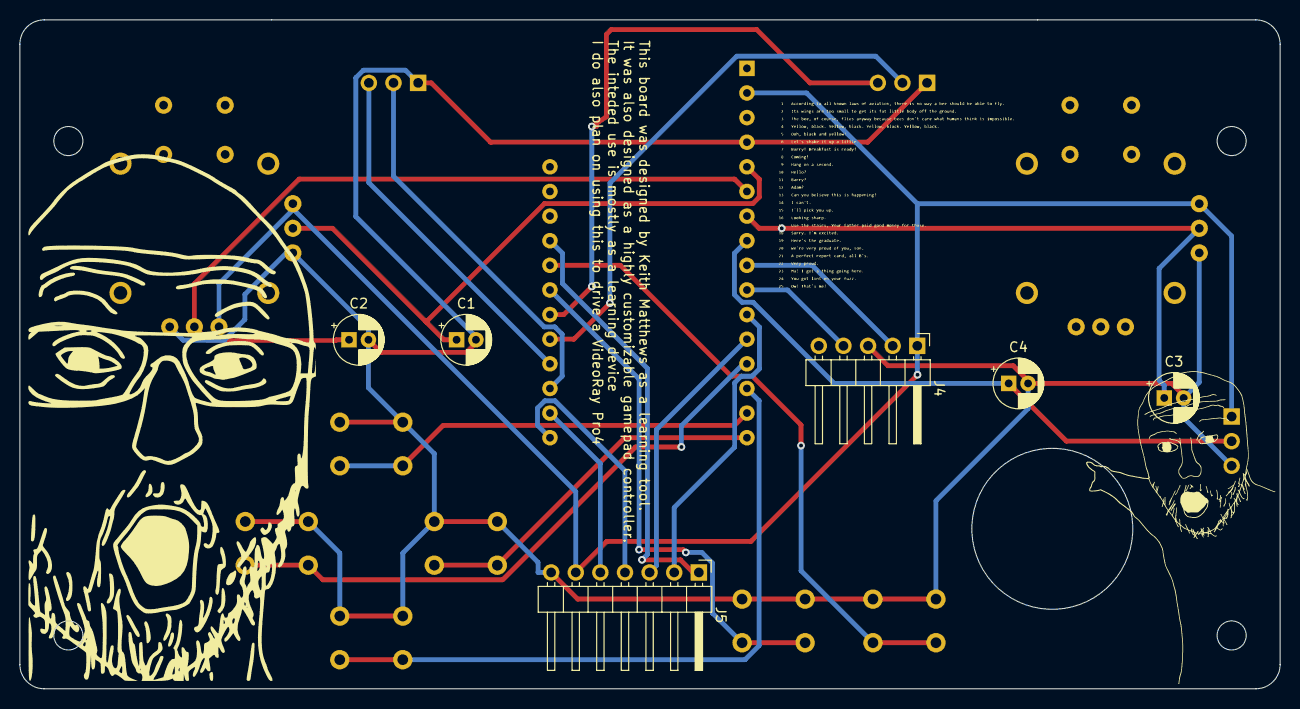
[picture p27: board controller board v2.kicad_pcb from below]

Board: 2 copper layers, 130.0 x 69.0 mm, 23 parts (9 on the bottom side), 23 nets.

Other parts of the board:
G34: LOGO; beemovie
G36: LOGO; Wojack1
G45: LOGO; Wojack2
REF15: OSHW-Symbol_13.4x12mm_SilkScreen
REF30: KiCad-Logo2_6mm_SilkScreen

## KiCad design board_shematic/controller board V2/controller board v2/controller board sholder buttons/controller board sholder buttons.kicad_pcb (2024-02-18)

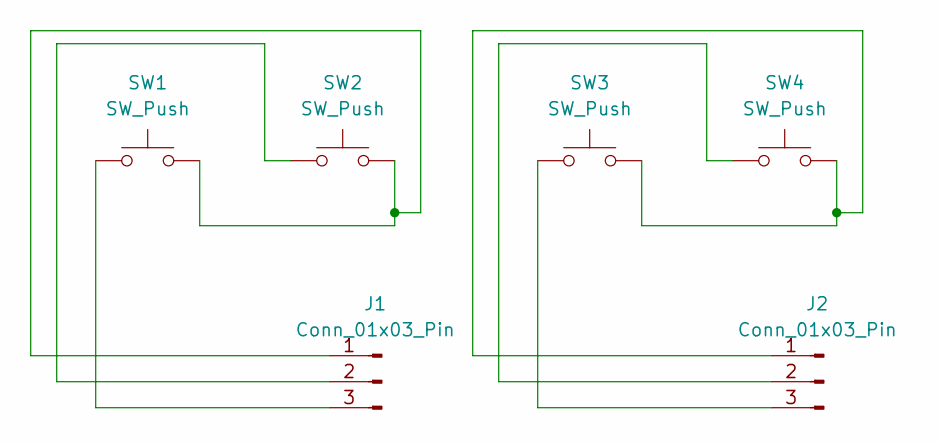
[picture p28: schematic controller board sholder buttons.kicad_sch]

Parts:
J1, J2: Conn_01x03_Pin; PinHeader_1x03_P2.54mm_Vertical
SW1, SW2, SW3, SW4: SW_Push; SW_PUSH_6mm_H5mm

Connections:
unnamed: J1.1, SW1.2, SW2.2
unnamed: J1.2, SW2.1
unnamed: J1.3, SW1.1
unnamed: J2.1, SW3.2, SW4.2
unnamed: J2.2, SW4.1
unnamed: J2.3, SW3.1

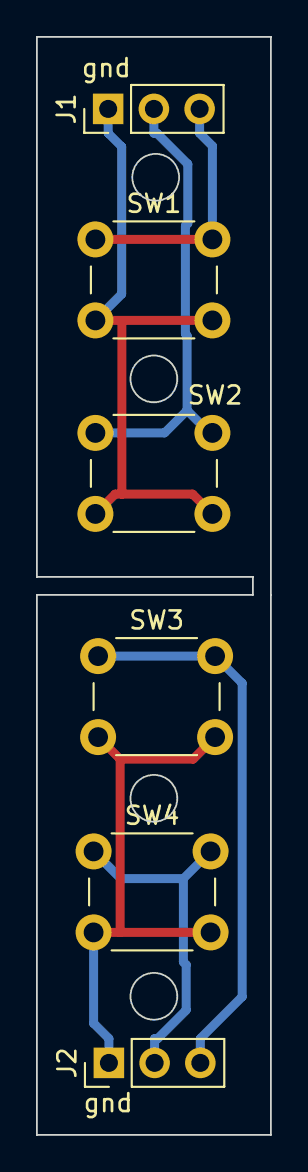
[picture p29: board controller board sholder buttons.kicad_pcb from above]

Board: 2 copper layers, 13.0 x 61.0 mm, 6 parts (0 on the bottom side), 6 nets.

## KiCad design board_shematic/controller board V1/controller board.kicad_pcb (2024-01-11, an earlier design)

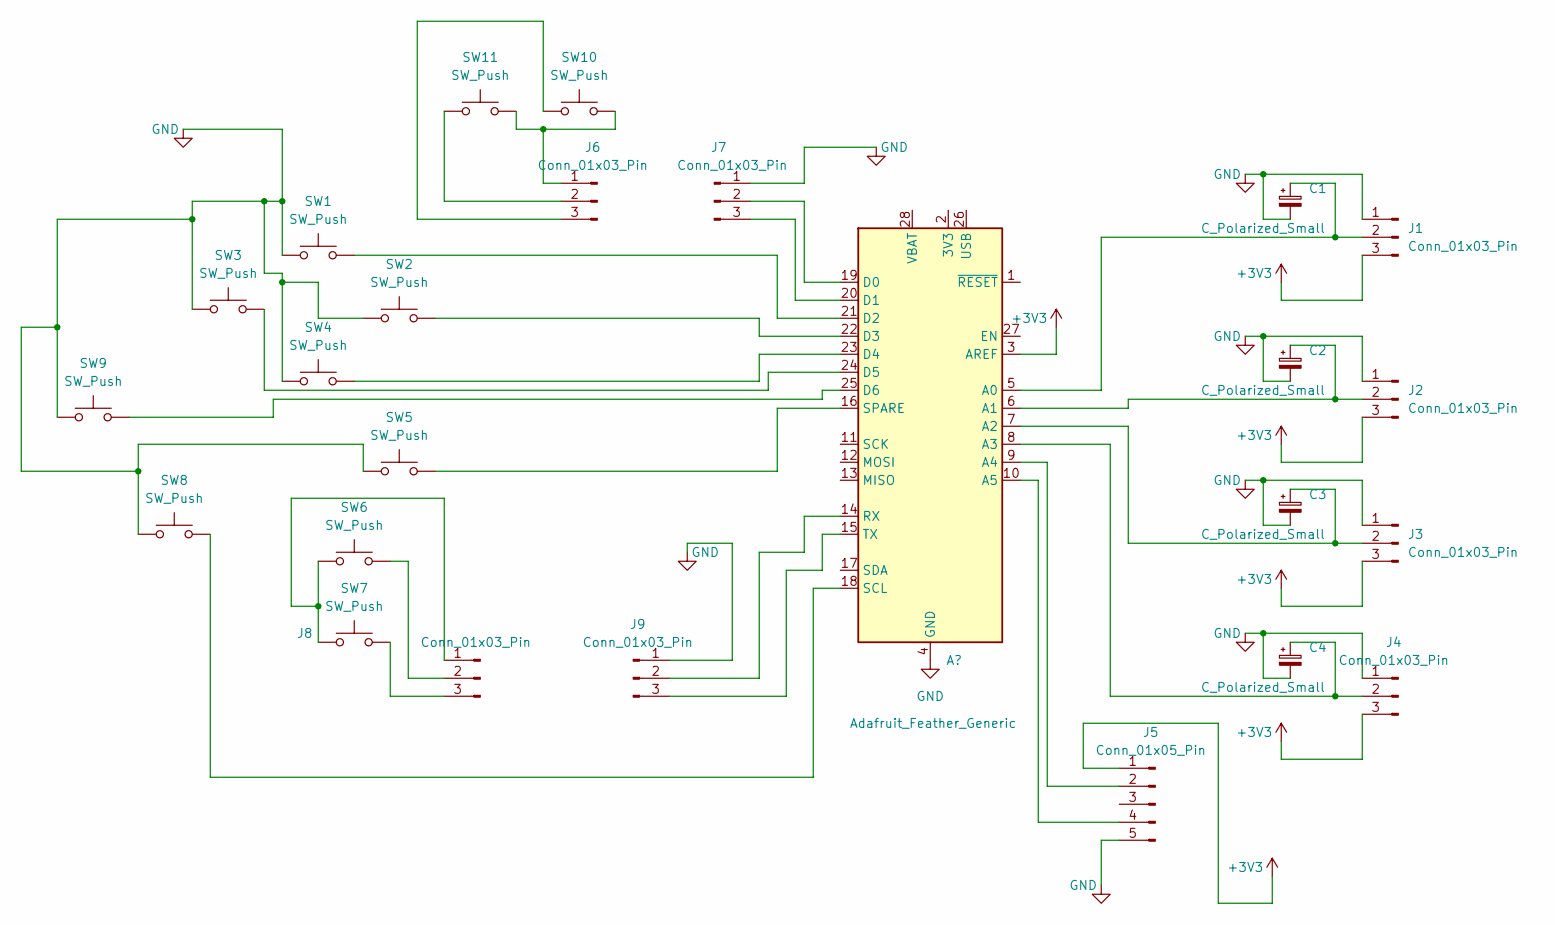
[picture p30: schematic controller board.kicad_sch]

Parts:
C1, C2, C3, C4: C_Polarized_Small; CP_Radial_D5.0mm_P2.00mm
J1, J2, J3, J4, J6, J7, J8, J9: Conn_01x03_Pin; PinHeader_1x03_P1.00mm_Vertical
J5: Conn_01x05_Pin; PinHeader_1x05_P1.00mm_Vertical
SW1, SW2, SW3, SW4, SW5, SW6, SW7, SW8, SW9, SW10, SW11: SW_Push; SW_SPST_SKQG_WithStem

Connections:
+3V3: J1.3, J2.3, J3.3, J4.3, J5.1; also elsewhere on the board
GND: C1.2, C2.2, C3.2, C4.2, J1.1, J2.1, J3.1, J4.1, J5.5, J7.1, J9.1, SW1.1, SW2.1, SW3.1, SW4.1, SW5.1, SW8.1, SW9.1; also elsewhere on the board
unnamed 2: C1.1, J1.2; also elsewhere on the board
unnamed 3: C2.1, J2.2; also elsewhere on the board
unnamed 4: C3.1, J3.2; also elsewhere on the board
unnamed 5: C4.1, J4.2; also elsewhere on the board
unnamed 6: SW5.2; also elsewhere on the board
unnamed 7: SW3.2; also elsewhere on the board
unnamed 8: SW9.2; also elsewhere on the board
unnamed 9: SW1.2; also elsewhere on the board
unnamed 10: SW2.2; also elsewhere on the board
unnamed 11: SW4.2; also elsewhere on the board
unnamed 12: J7.3; also elsewhere on the board
unnamed 13: J7.2; also elsewhere on the board
unnamed 14: J5.2; also elsewhere on the board
unnamed 15: J5.4; also elsewhere on the board
unnamed 16: J9.2; also elsewhere on the board
unnamed 17: SW8.2; also elsewhere on the board
unnamed 18: J9.3; also elsewhere on the board
unnamed: J6.1, SW10.2, SW11.2
unnamed: J6.2, SW11.1
unnamed: J6.3, SW10.1
unnamed: J8.1, SW6.1, SW7.1
unnamed: J8.2, SW6.2
unnamed: J8.3, SW7.2

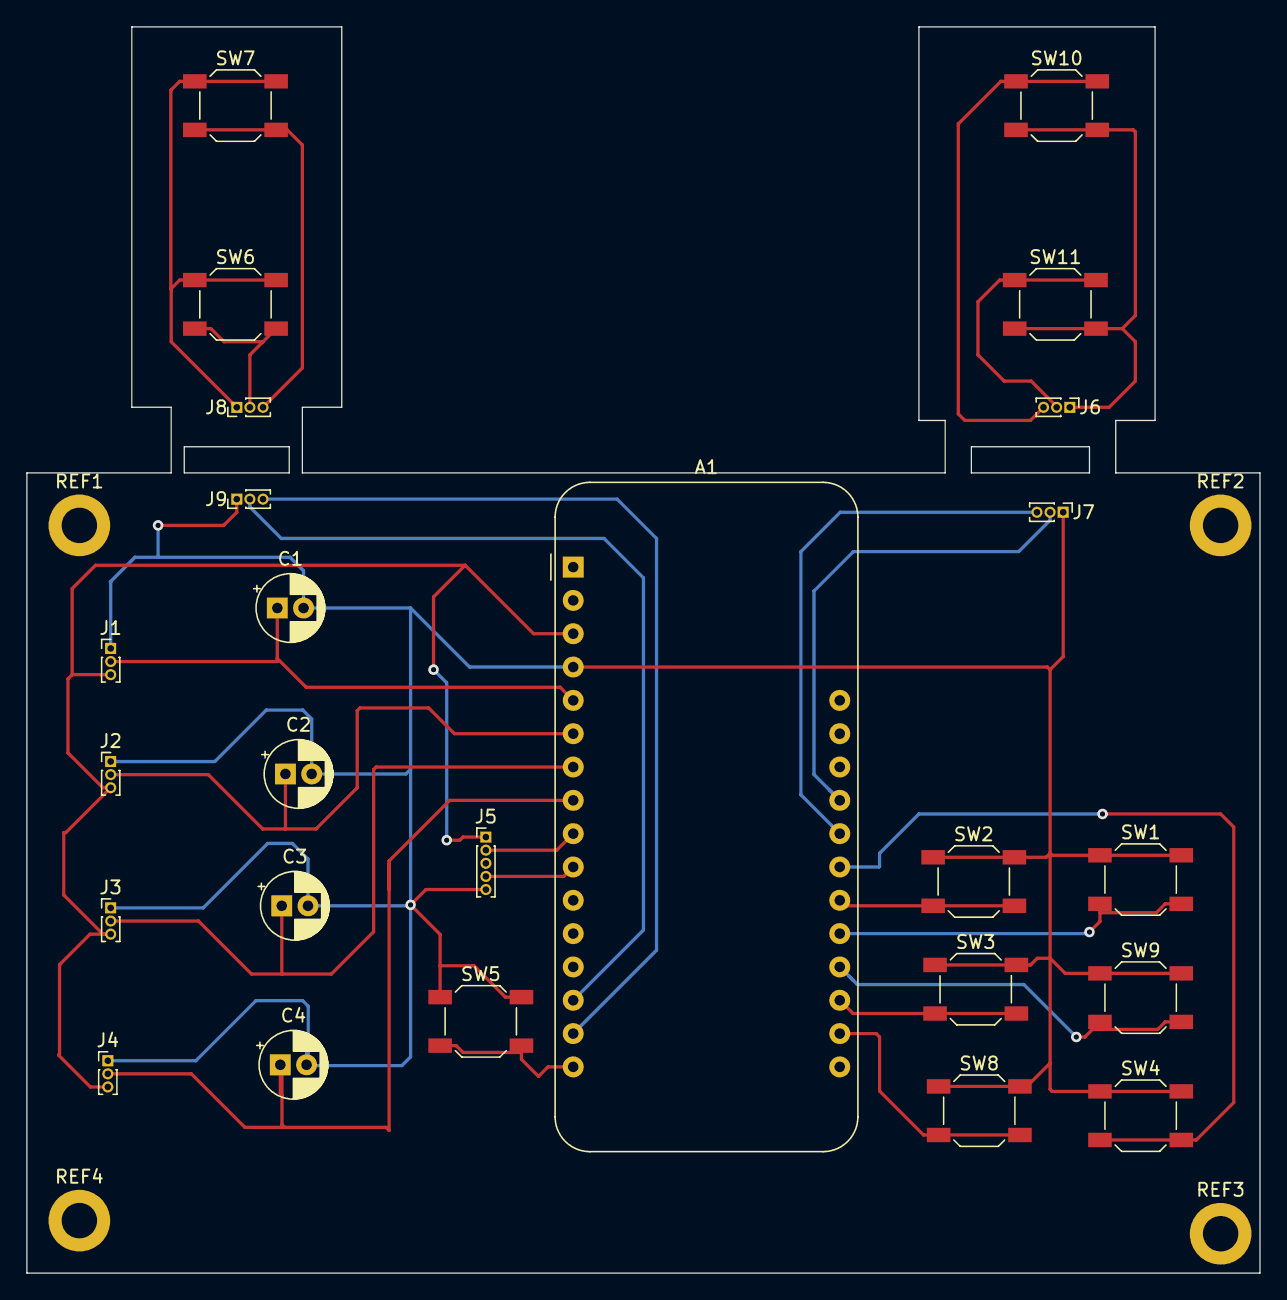
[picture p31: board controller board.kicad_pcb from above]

Board: 2 copper layers, 94.0 x 95.0 mm, 29 parts (0 on the bottom side), 25 nets.

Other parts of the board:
A1: Adafruit_Feather_Generic; Adafruit_Feather
REF1, REF2, REF3, REF4: MountingHole_2.7mm_M2.5_DIN965_Pad

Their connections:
+3V3: A1.3 (3V3); also elsewhere on the board
GND: A1.4 (GND); also elsewhere on the board
unnamed 2: A1.5 (A0); also elsewhere on the board
unnamed 3: A1.6 (A1); also elsewhere on the board
unnamed 4: A1.7 (A2); also elsewhere on the board
unnamed 5: A1.8 (A3); also elsewhere on the board
unnamed 6: A1.16 (D4); also elsewhere on the board
unnamed 7: A1.19 (D5); also elsewhere on the board
unnamed 8: A1.20 (D6); also elsewhere on the board
unnamed 9: A1.21 (D9); also elsewhere on the board
unnamed 10: A1.22 (D10); also elsewhere on the board
unnamed 11: A1.23 (D11); also elsewhere on the board
unnamed 12: A1.24 (D12); also elsewhere on the board
unnamed 13: A1.25 (D13); also elsewhere on the board
unnamed 14: A1.9 (D24); also elsewhere on the board
unnamed 15: A1.10 (D25); also elsewhere on the board
unnamed 16: A1.14 (RX); also elsewhere on the board
unnamed 17: A1.18 (SCL); also elsewhere on the board
unnamed 18: A1.15 (TX); also elsewhere on the board

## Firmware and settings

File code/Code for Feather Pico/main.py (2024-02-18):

import board
import microcontroller
import digitalio
from analogio import AnalogIn
from joystick_xl.inputs import Axis
from joystick_xl.inputs import Button
from joystick_xl.joystick import Joystick

# Setup LED and Button
led = digitalio.DigitalInOut(board.D24)
led.direction = digitalio.Direction.OUTPUT
button = digitalio.DigitalInOut(board.D25)
button.switch_to_input(pull=digitalio.Pull.UP)

# Define axis configuration constants
AXIS_DB1 = 10  # Deadband to apply to axis center points.
AXIS_DB2 = 100
AXIS_MIN = 0  # Minimum raw axis value.
AXIS_MAX = 65535  # Maximum raw axis value.

# Create Joystick instance
joystick = Joystick()

# Create AnalogIn instances for analog inputs
analog_z_button = AnalogIn(board.A2)
analog_z_no_button = AnalogIn(board.A3)
flip_x = AnalogIn(board.A1)
flip_y = AnalogIn(board.A0)

# Add an Axis to the joystick with specified deadband and range with the board pin defined, these become "hardcoded" and you cant mess with them. if defined like the z axis, you can mess with them in code
# if you need access to special pins that are reserved as something aside from digitalio like the MOSI, and MISO pins you can call for them using the microcontroller.pin.gpio# decleration to call them as digitalio
joystick.add_input(
    Button(board.D5),  #1
    Button(board.D6),  #2
    Button(microcontroller.pin.GPIO20), #3
    Button(board.D10),  #4
    Button(),  #5
    Button(board.D12),  #6
    Button(board.D1),  #7
    Button(board.D0),  #8
    Button(board.D9),  #9
    Button(board.D4),  #10
    Button(),  #11
    Button(board.D11),  #12
    Axis(deadband=AXIS_DB2, min=AXIS_MIN, max=AXIS_MAX),
    Axis(deadband=AXIS_DB2, min=AXIS_MIN, max=AXIS_MAX),
    Axis(),
    Axis(),
    Axis(),
    Axis(deadband=AXIS_DB1, min=AXIS_MIN, max=AXIS_MAX)

)

def map_value(raw_value, in_min, in_max, out_min, out_max):
    """
    Map the input value from one range to another.

    Parameters:
    - raw_value: The raw input value to be mapped.
    - in_min: Minimum value of the input range.
    - in_max: Maximum value of the input range.
    - out_min: Minimum value of the output range.
    - out_max: Maximum value of the output range.

    Returns:
    - Mapped value within the specified output range.

    Additional notes:
    if you invert the out_min and out_max values this will invert the axis inputs
    """
    # Map the input value using a linear mapping formula
    return int((raw_value - in_min) * (out_max - out_min) / (in_max - in_min) + out_min)

while True:
    led.value = button.value
    

    if button.value:
        # Map analog_x_button value within the specified range
        z_value = map_value(analog_z_button.value, 0, 65535, 0,  65535 )
    else:
        # Use raw analog_x_no_button value when the button is not pressed
        z_value = analog_z_no_button.value

    # Ensure the mapped value is an integer
    z_mapped = int(z_value)
    x_flipped = int(map_value(flip_x.value, 65535, 0, 0,  65535 ))
    y_flipped = int(map_value(flip_y.value, 65535, 0, 0,  65535 ))
    # Update the joystick axis with the mapped value
    joystick.axis[0].source_value = x_flipped
    joystick.axis[1].source_value = y_flipped
    joystick.axis[5].source_value = z_mapped
    joystick.update()

    # Add more logic for buttons, triggers, etc.

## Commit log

2024-01-11 Initial Commit of Controller Repo
    [4884 Feather RP2040(1).step, Adafruit Feather RP2040.sch, COM-09032.step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]
2024-01-12 work on ensuring board is made correctly
    [controller board v2.kicad_pcb]
2024-01-12 Updates to PCB design
    [controller board v2.kicad_pcb, controller board v2.kicad_sch]
2024-01-13 added credits file, added 3d model for 10k pot
    [controller board v2.kicad_pcb, controller board v2.step]
2024-01-14 modified sholder buttons
    [916 Metal Button 19mm metal button, on off switch.step, controller board sholder buttons.kicad_pcb, controller board sholder buttons.step]
2024-01-14 changed hole locations, updated pin orientation
    [controller board sholder buttons.kicad_pcb, controller board sholder buttons.kicad_sch, controller board sholder buttons.step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]
2024-01-14 minor edits to pcb, end of night
    [controller board sholder buttons.kicad_pcb, controller board v2.kicad_pcb, controller board v2.kicad_sch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]
2024-01-16 updated folder structure, removed un-needed stuff
    [4884 Feather RP2040.step, Controller body - Part 1.3mf, Part Studio 3 - Part 1.3mf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]
2024-01-19 added 3d models of Controller
    [Controller body - Part 1.3mf, Controller body - button.3mf, Controller body - top shell.3mf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]
2024-01-21 3d models work
    [Controller prusa slicer project.3mf]
2024-02-18 added images and 3d model revisions
    [Controller body - faceplate.3mf, Controller body - top shell.3mf, Sholder buttons - button face left1.3mf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]
2024-02-18 added a bunch of images, CAD Changes
2024-02-18 cleaned up file structure, got rid of extra stuff
    [4884 Feather RP2040(1).step, 4884 Feather RP2040.step, 916 Metal Button 19mm metal button, on off switch.step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]
2024-02-22 lots of updates to readme
    [controller board v2.kicad_pcb, controller board v2.kicad_sch]
